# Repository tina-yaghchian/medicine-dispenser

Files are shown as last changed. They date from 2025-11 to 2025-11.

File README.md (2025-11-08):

# 💊 Automated Medicine Dispenser

[]()


An embedded **medicine dispenser** using two STM32 Nucleo-F401RE boards (UART), a **servo-driven** rotating mechanism, and a **hatch** for timed dispensing.

## 🗺️ System Diagram
System Architecture

## 💡 Idea Sketch
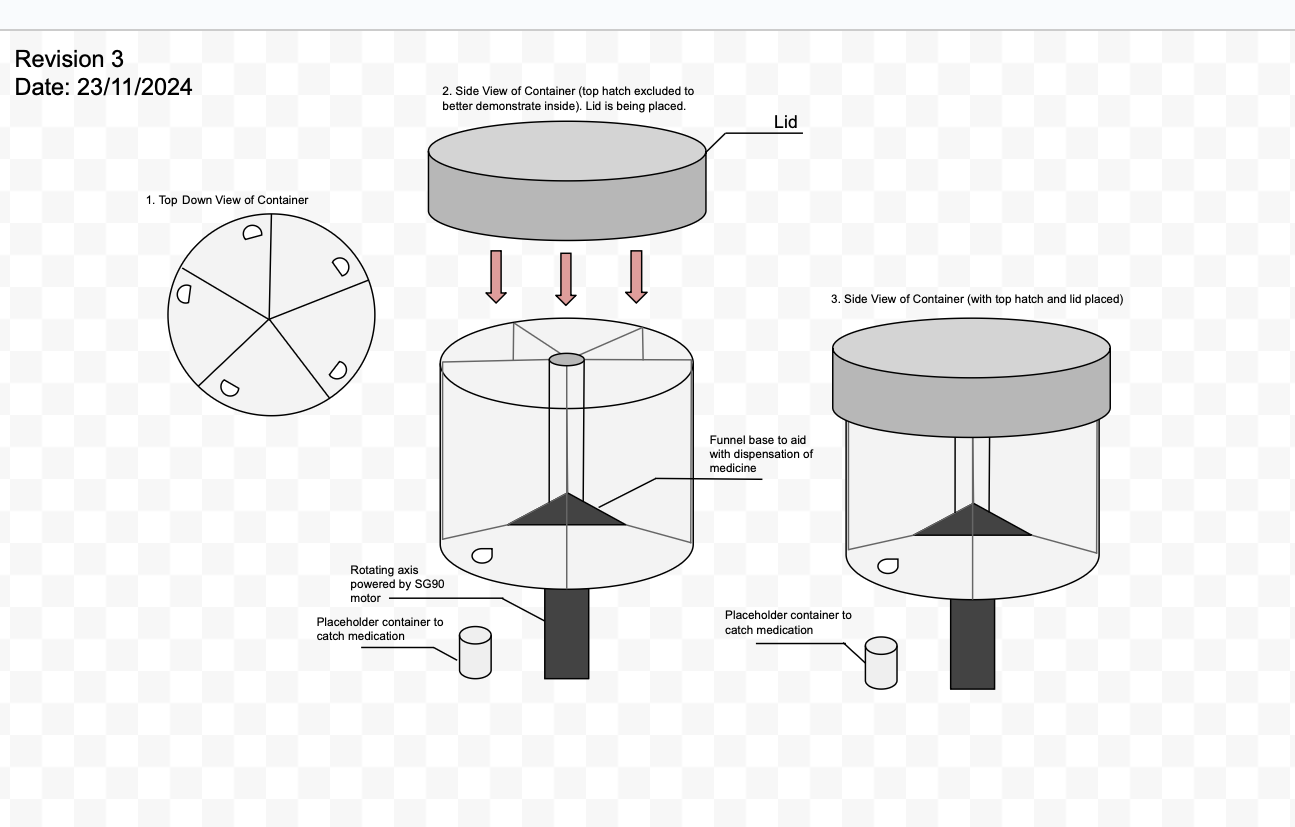
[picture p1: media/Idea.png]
Concept sketch


## 💊 CAD Models

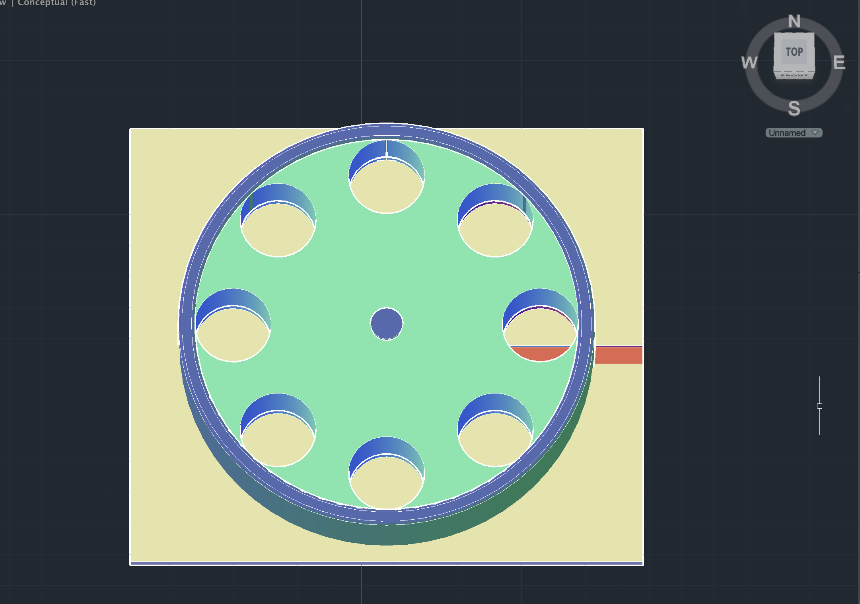
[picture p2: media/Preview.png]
3D Modeling


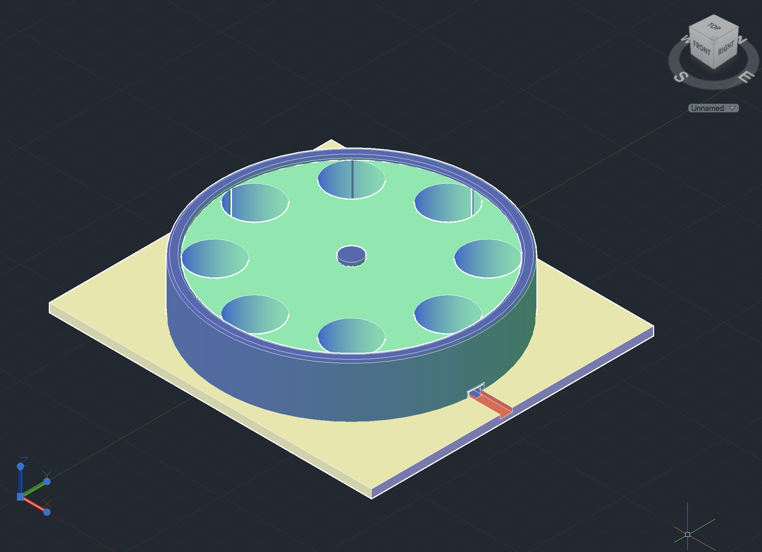
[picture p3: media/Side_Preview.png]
3D Modeling (side)


[medicine_dispenser.dwg](./medicine_dispenser.dwg) | Final 3D AutoCAD assembly

> Designed and modeled in AutoCAD Desktop.

## 📦 Repo Structure
```
hardware/      CAD + circuits
firmware/      Board projects (input & dispenser)
docs/          Design report, test plan, manuals
media/         Photos, diagram, demo video
```

## ⚙️ Build & Flash (STM32CubeIDE)
1. Clone repo and open **STM32CubeIDE**.
2. Import `firmware/uart_controller` and `firmware/motor_driver` as existing projects.
3. Set toolchain to **Debug** (or Release), then **Build**.
4. Connect each Nucleo-F401RE via USB and **Run → Debug** (or **Run**) to flash.

### UART (example settings)
- Baud: 115200, 8N1
- Wire **GND–GND**, **TX(Board1) → RX(Board2)**
- Distance: 1–15 m (project spec)

## 🔌 Pins (example — adjust for your boards)
**Input Board**
- Buttons: PB0..PB7 (w/ 10 kΩ pulldowns)
- UART TX: PA2, RX: PA3 (typical)

**Dispenser Board**
- Servo (hatch): PB6 (PWM)
- Servo (rotation): PB7 (PWM)
- UART RX: PA3, TX: PA2

## ▶️ Demo Video (inline)
<!-- GitHub can render .mov; include HTML video tag for inline playback -->
<video src="media/Test.mov" width="640" controls></video>

If your browser doesn’t autoplay inline, download: [Test.mov](media/Test.mov)

## 📸 Prototype
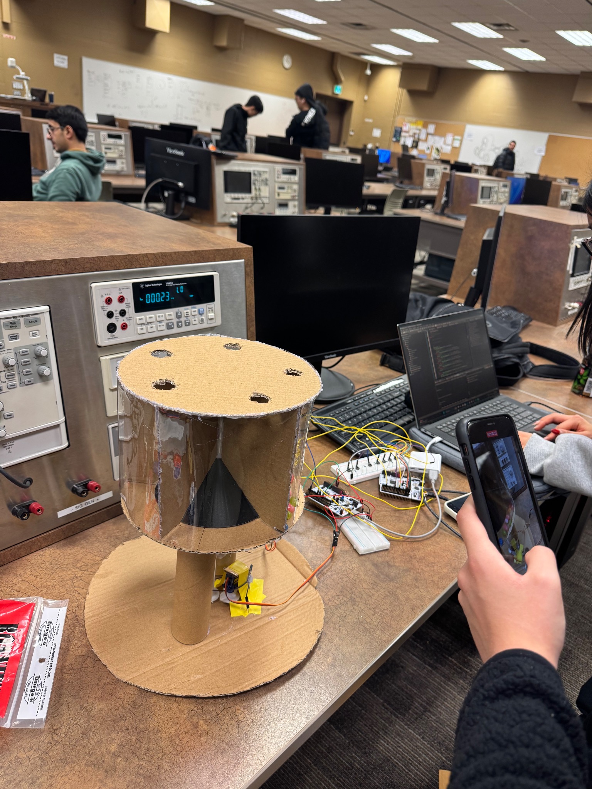
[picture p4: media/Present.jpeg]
Physical prototype in lab


## 🔌 Circuit Diagram
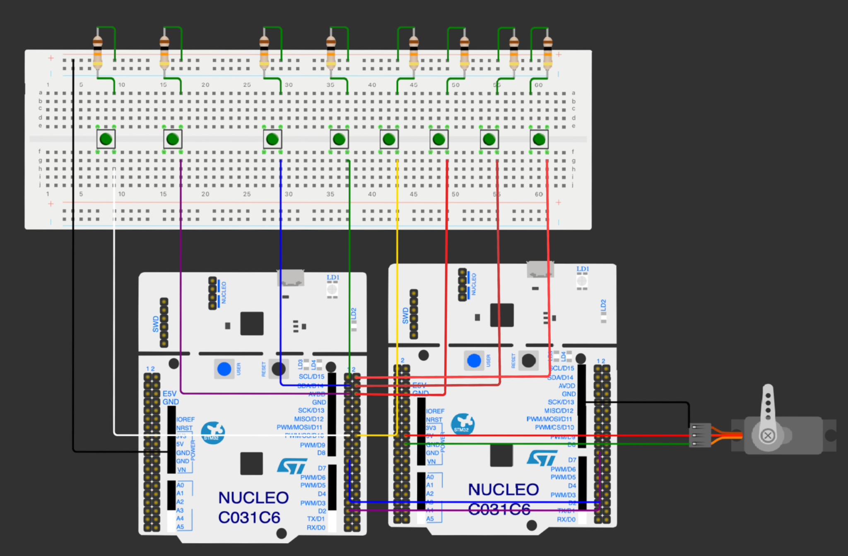
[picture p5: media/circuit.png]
Circuit diagram


## 🧪 Tests
- Communication ≥ 1 m
- Each of 5 compartments dispenses
- Accuracy within ±1 pill
- Supports 1–22 mm pills
- Total time < 10 min

## 🧰 Hardware & Tools
| Component | Model | Quantity | Function |
|---|---|---|---|
| Microcontroller | STM32 Nucleo-F401RE | 2 | Control & communication |
| Servo Motor | SG90 | 2 | Hatch & rotation control |
| Push Buttons | 6x6mm DIP | 8 | User input interface |
| Power Adapter | 5V DC | 1 | Power supply |
| Material | Polycarbonate (3D printed) | — | Mechanical structure |
| Software | AutoCAD, SolidWorks, STM32CubeIDE, Fritzing | — | Design & implementation |

## 📚 Docs
- Design Document: see `docs/` (add PDF version when ready)
- Test Plan: `docs/Test_Plan.md`

## 🚀 Future Improvements
- LCD display for scheduling and feedback
- BLE/Wi‑Fi companion app
- Stepper motor + home sensor
- Injection‑molded enclosure

## 🏁 License
MIT License © 2025 – Tina Yaghchian

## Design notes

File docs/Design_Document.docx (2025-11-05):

Design Document for a Medication Distribution Device to Aid Caretakers in Dispensing Medication

Parto Tolouashtiany, Tina Yaghchian, Ashley Moon

University of Waterloo

October 30, 2024

Needs Assessment

Customer & Challenge Definition

Client: Hospitals Nurses

Hospital Nurses: Employed nurses who work at a hospital to provide care to needed patients [1]

The Hospital Nurses that we are targeting are:

- Located in Canada
- Nurses in understaffed hospitals
  - A significant percentage of Canadian nurses have high work demands due to the limitation of nurses in hospitals, making them more prone to error. [2]
- Nurses in hospitals serving a demographic of elderly or chronically ill patients that require multiple dosages of pills and careful scheduling

Challenges

Medication error is a commonly made mistake made by hospital nurses due to the complexity of managing multiple medications, time pressures, and the risk of miscommunication which involves losing/misplacing pills or treating medicine at the wrong time.

According to reports, around 1/5 of registered nurses employed in a hospital admitted that medication errors occur “occasionally” or “frequently”. [3] More precisely, medication error was reported to exist among 57.4% of nurses. [4] This is likely due to high patient loads and the time constraints of such hospital environments which pose challenges in ensuring precise medication administration.

Competitive Landscape

To address the challenge associated with medication errors made by hospital nurses, here are three existing social, economic, and technological systems and how they address the challenges and their shortcomings.

1. Electronic Health Records Systems (EHR)

Electronic health record is a secure record that includes all of a patient’s health history. [5]

This system is also used to streamline medication management through automated alerts for medication reminders, advisories and alerts. However, there are shortcomings to this system. While EHR Alerts have been implemented to reduce miscommunication between nurses and effectively stay up to date with the medication schedule, they have been identified to cause alert fatigue and overload, leading to frustration. This ultimately leads to nurses ignoring important notifications, potentially resulting in oversights [6] .

2. Clinical Decision Support Systems (CDSS)

Clinical decision support systems assist healthcare providers by offering clinically relevant advice based on specific patient data. This system is also widely used to detect errors such as missing a prescribed medication or wrong dosages, ensuring patient safety. [7] This system, while effective, has had its pitfalls as listed below:

- Alert fatigue and inappropriate alerts
  - Research indicates that 95% of alerts generated by clinical decision support systems are often deemed irrelevant by physicians, leading to many alerts being ignored [8]
- Financial challenges
  - Financial barriers present a significant challenge, as approximately 74% of organizations utilizing CDSS report struggling with the cost-effectiveness of implementation [8]
3. Barcoding Medication Administration (BCMA) Systems

Barcoding Medication Administration (BCMA) systems are used primarily in hospitals to ensure that nurses and caregivers administer the correct medication to the right patient at the correct time. The system involves scanning barcodes on both patient wristbands and medication packaging, which helps reduce medication errors and enhances patient safety. [9] However, BCMA systems have several limitations. Training nurses and staff to use these systems can be time-consuming, impacting hospital resources. Additionally, the scanning process can slow down workflow, especially during busy shifts, and can feel tedious for nurses who must repeat this process multiple times daily.

Requirement Specification

Functional Requirements:

Aim of the System:

1. To contain and prepare 5 or more daily drugs to be administered to a patient.

- This number is based on the fact that around 1 in 5 adults aged 40-79 years in the United States and Canada use at least 5 prescription drugs. [10]
- Additionally, among this figure, it was more common for adults aged 60-79 to be taking 5 or more prescription drugs (in the US these figures were 34.5% vs. 14.5% and in Canada 30.9% vs. 10.4%) [11]

It is likely that caretakers who need to deal with multiple medications are those that struggle the most with organization, time allocation and medication accuracy when doing medication management. Our solution would most beneficially impact the sizably large population which need multiple medications (5+) managed by informal caretakers.

- To put into context, approximately 98% of aged 65 and older who receive publicly funded long-term home care services have informal caretakers [12]

2. To maintain accuracy when dispensing medication

As this device is a medical one, it is of the utmost importance that its margin of error be extremely minimal. The device is meant to eliminate common human error and as such cannot afford to make common mistakes. Ideally, it would have 100% accuracy when dispensing pills. However, this may not be the case, and as such, the lowest possible margin of error is ±1 pill in some test cases.

- To justify the need for such minimal errors, the gravity of them may be put into context: the Institute of Medicine (IOM) Committe on Quality of Health Care in the United States that medical errors are a leading cause of death and injury. [13]
- Further, medication errors themselves are the most common, preventable cause of patient injury. [14]

3. Confirmation indicator

Previous requirement: To indicate to the patient that their pills have been dispensed. This is done through audible and visual alert.

- The audible alert should be at a volume of 70 dB, as any volume above this is considered to cause a risk of hearing loss. [15]
- The volume was chosen to be at the very edge of the barrier to risk because an estimated 54% of Canadians aged 40-79 are reported to have hearing loss, which may make the alert less effective if the volume was lower [16]

We decided to remove this functional requirement as we figured that the pill dispenser should be efficient enough to be dispensed in a short amount of time, disregarding the need for an indicator. Furthermore, we determined that the sound produced by the gears during operation would be a sufficient indicator that the pill dispensing process has been completed. This auditory cue disregards the need for any additional signifiers.

Instead, we decided that the implementation of a confirmation button in the dispenser that finalizes the chosen number of pills could add an extra-step of user verification. This extra security reduces the risk of accidental pill dispensing and allows the user to confirm the initiation of the device. Confirmation buttons help reduce uncertainty and enhance accuracy before proceeding with any action [17]

4. To reduce the time spent sorting medications. The device is meant to eliminate a large burden on informal caretakers.

- An average of 1-3 hours is spent sorting prescription medications each week. [18]
- To minimize this time, the device needs to work efficiently and finish its task of dispensing pills at a faster rate. To minimize impatience, and demonstrate the devices efficiency, dispensing should take no more than 10 minutes at most.

Technical Requirements:

1. Communication

To communicate between two microcontrollers at a minimum distance of 1 meter between them. Additionally, the distance between them should not exceed a distance of 15 meters.

This is to reduce issues regarding signal degradation and interference as the microcontrollers will use UART communication, which is most reliable at shorter distances. Additionally, this range falls into the standard used for RS –232 serial communications, which while are not exact to what is being used here, can be a helpful comparison [19]

### 2. Pill Compartments: Preparing the Drugs

Regarding the pill compartments in our medical dispenser, we must consider the following components:

1. Flexibility: To cater to all pill sizes, the opening mechanism of the dispenser should be able to dispense multiple of any sized pill. Typically, pills are standardly less than around 5mm in diameter but can also range from 1mm to 22mm. The largest measurement we have is 22 mm, so the opening mechanism should be able to dispense pills up to that size.[20]

Previous Requirement: Adjustability

Adjustability: To cater to all pill sizes the pill-holding compartments should be either adjustable or flexible to ensure that a range of medications can be stored efficiently. Typically, pills are standardly less than around 5mm in diameter but can also range from 1mm to 22mm. The largest measurement we have is 22 mm, so the compartments should be able to sort pills up to that size.[20]

We decided to adjust this requirement because the ability to hold multiple types of pill components did not effectively account for dispensing the varying sizes of different pills.

2. Storage: Each pill compartment should have a secure locking mechanism to prevent spillage or unauthorized pill access. This is critical as unsecure access to medicine poses a risk to unprescribed individuals. For instance, reports indicate that approximately 50,000 children each year accidentally ingest medications without adult supervision, leading to emergency room visits. [21]

### 3. Software

The software used in a medicine dispenser plays a critical role in ensuring that caregivers and patients can easily program doses, set time schedules, and configure alarms. A well-designed, easy-to-navigate interface helps prevent errors and enhances user experience, particularly for non-technical users such as elderly patients or caregivers.

The software interface should be simple and straightforward, with clear instructions and logical flow. This reduces the likelihood of errors when setting doses or alarms. Buttons, icons, and labels should be large and easy to read, especially for users with visual impairments. [22]

4. Low Power Operation

Previous requirement: High Accuracy Sensors

A fundamental technical aspect of the medicine dispenser relies on sensor technology. To accurately dispense the pills and track the quantity of pills dispensed, we plan on using weight sensors.

A weight sensor is a type of transductor that measures weight. It transforms mechanical forces such as load, weight, tension, compression, or pressure into an electrical signal which is applied based on the force applied. [23]

For our dispenser, the weight sensor will convert the mechanical force of the pill’s weight into an electrical signal. Given that the average weight of American tablets range between 0.22g and 0.3235g, the weight sensor will be designed to measure forces within in range, with an accuracy of ± 0.001g. [24]

We decided to remove this technical requirement because the sensor sensitivity required for accurate weight measurement could not be achieved, as weight sensors are not precise enough for our needs. Thus, we decided to change this technical requirement to low-power operation.

Our medical dispenser is created with the intention of long-term and continuous use in hospital settings, making minimal energy consumption a must. The minimization of energy consumption can ensure an efficient, reliable, and safe operation of the medical dispenser with reduced wear and tear. [25]

For our dispenser, we set the power limit to be under 30 watts.

Safety Requirements:

1. Protective Cover

Previous requirement: Alarm

There should be an alarm in case the dispenser detects a malfunction within a short amount of time (Under 1 minute). It should ensure the dispenser accurately measures and dispenses the correct dosage. It is necessary to implement systems to alert caregivers and patients if a dosage is missed or incorrect. There should be large indicators for dosage and timing information and Intuitive controls to minimize user errors. [26]

We decided to omit the alarms as we decided to remove the high-accuracy sensors. Instead, we decided to implement a protective cover over the dispenser’s release area that only opens when dispensing the medication. This enhances safety by reducing the risk of accidental spills or unintended access, as covers and seals can effectively contain all spillage. [27]

2. Voltage Limit

Based on the safety guidelines for low-voltage electrical systems, there should be a limit to the voltage that the system uses (<50V) to avoid electrical hazards. A backup battery or an alternative power source must be included to ensure the dispenser operates during power outages. [28]

Analysis Assessment

Design

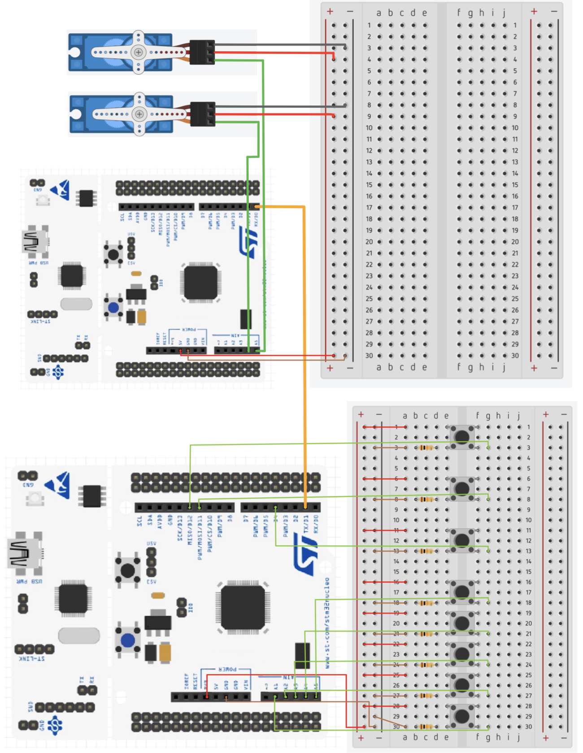
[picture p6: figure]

Design graphics used from Tinkercad and Fritzing software

Alternative Designs

1. Dispenser with Separated Funnel Containers

An alternative design which was considered had the containers of the dispenser fully separated. Instead of a large cylindrical container partitioned by 5 walls, 5 containers would be held aloft independent of each other. Tubing from each would join together into one larger tube, which would then dispense medication. Each container would have its own motor, which would open a hatch, allowing pills to be dispensed.

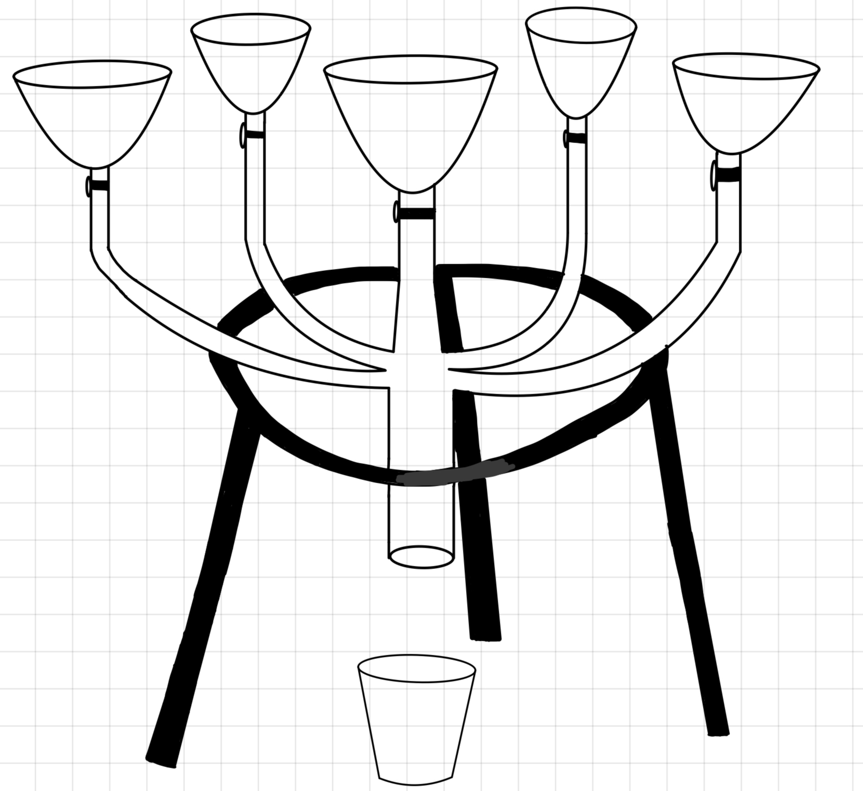
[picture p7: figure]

Alternative 1: Rough Diagram for Visualization

It was decided that this design would use an unnecessary number of motors. This would use a greater amount of energy and make the mechanism more complex, giving it more potential points of failure if anything malfunctioned.

2. Dispenser with Individual Rotating Containers

Another alternative was to have 5 individual containers which would rotate on top of a flat, stationary plate. Instead of a large cylinder divided by 5 walls, the separate containers would be attached to the moving axis directly. The containers would move over the hatch to dispense medication.

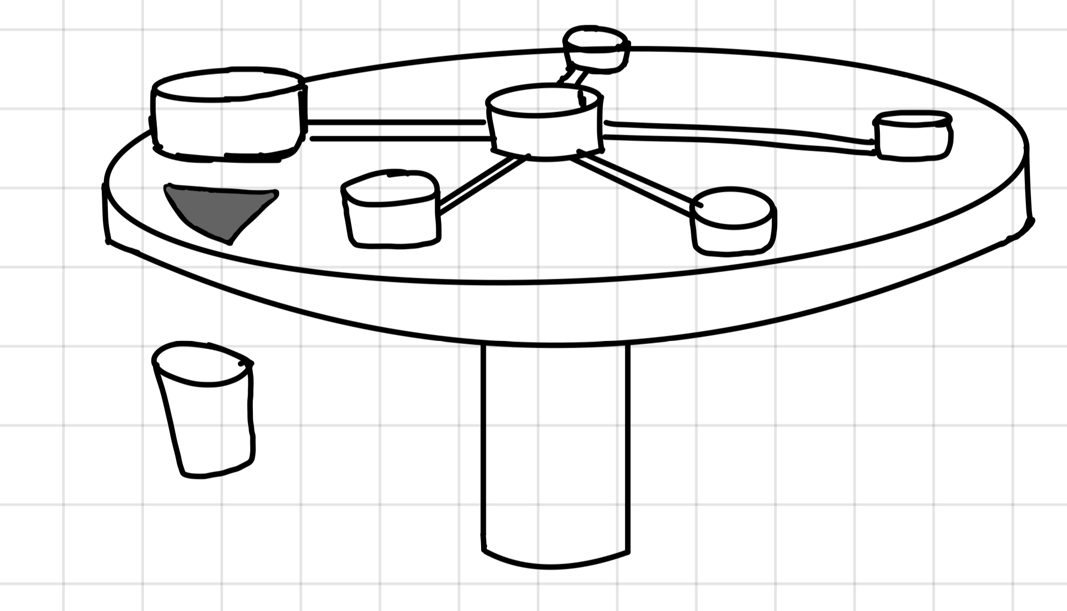
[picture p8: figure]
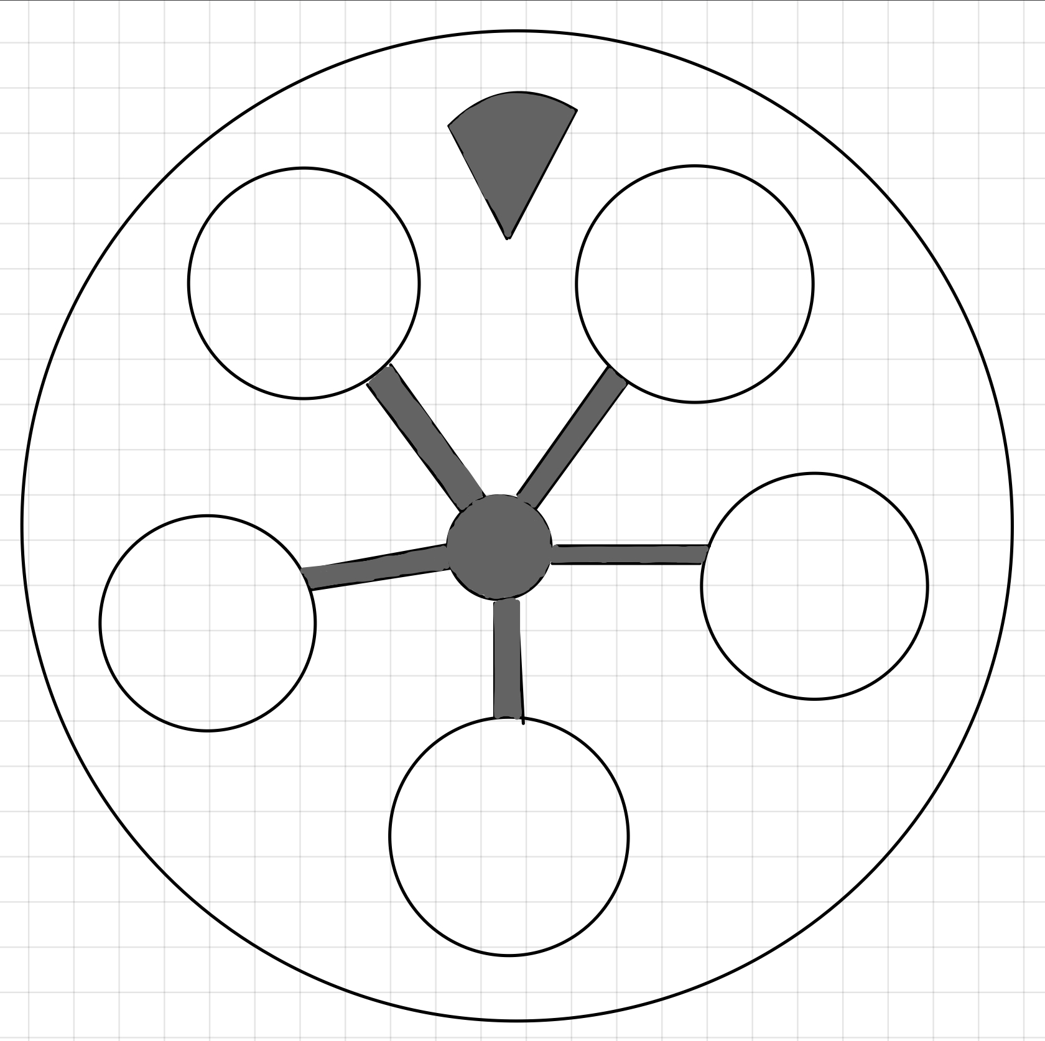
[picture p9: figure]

Alternative 2: Rough Sketch of Side View and Bird’s Eye View Perspectives

It was determined that this design does not efficiently use space and materials. It holds a much smaller volume of pills than the finalized design. This would cost a user more time when using the device, as they would have to restock it more often.

3. Dispenser with Rotating Container to Catch Pills Instead of Rotating Pill Compartments

This alternative would have had the pill containers stay stationary on a fixed metal plate. Each container would have a hatch underneath, where it would deposit pills into a cup underneath. The cup itself would be able to rotate, moving positions to underneath each hatch.

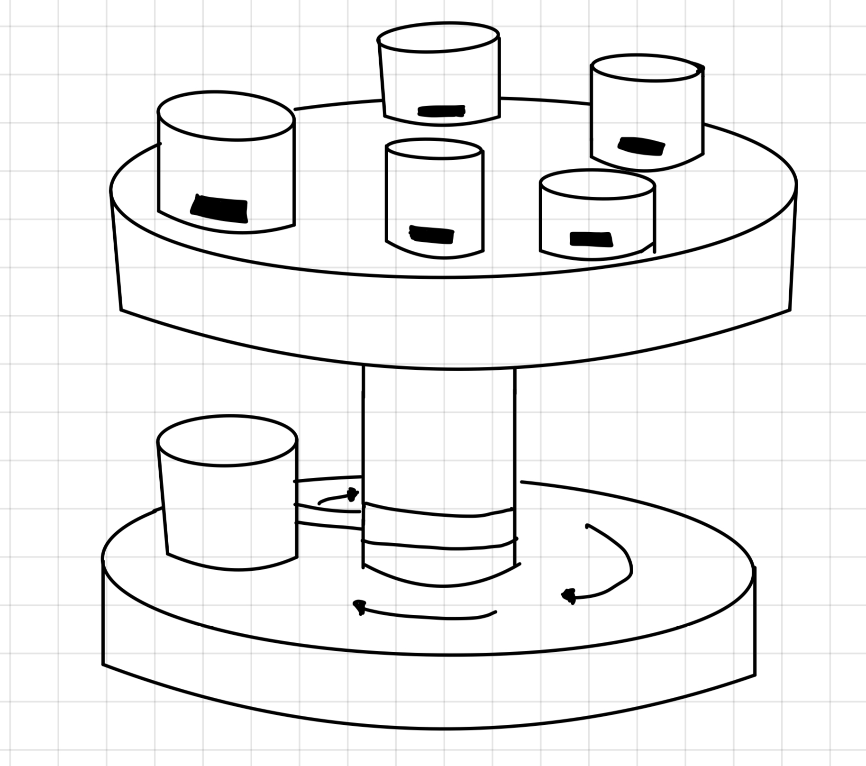
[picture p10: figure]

Alternative 3: Rough Diagram for Visualization

This alternative posed a similar issue to alternative 1. Instead of programming one hatch, now 5 would need to be programmed with 5 motors, in addition to creating a mechanism which would allow the cup to move. This would introduce too many variables and potential points of failure, making the solution too complex.

4. Dispenser using a Stepper or Gear Box Motor

This alternative is extremely similar to the finalized design, however instead of using a servo, a stepper or gearbox motor was to be used instead. After much deliberation, it was determined both motors would be too complex, needing a driver whose current would have to be limited to meet the specifications of the project. By contrast, the servo could be plugged directly to the microcontrollers, using less energy and working effectively if used with gears at a 1:2 ratio. As such, this alternative is almost the same as the finalized design, however, does not include gears and requires 2 drivers and far more extra code.

5. Horizontal Version of the Dispenser

Briefly, an alternative version of the final design was considered where, instead of the cylinder being vertical, it was instead horizonal. The walls would shift the pills up and down around the axis instead of circling around. The hatch would be on the walls of the cylinder instead of its floor.

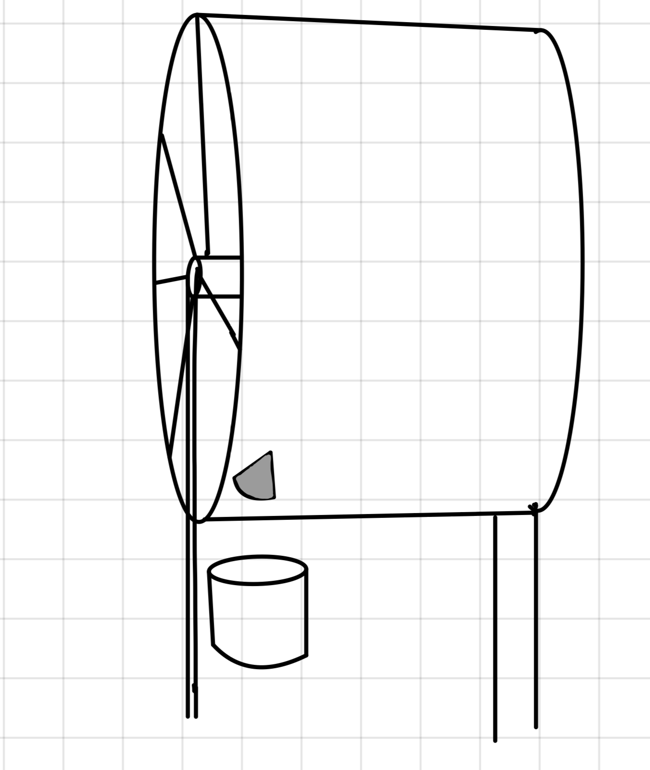
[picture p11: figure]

This design was ultimately not used as it was deemed more difficult to execute. The hatch would have to be curved to match the walls of the cylinder which would be more difficult to manufacture. Further, more torque would be needed by the motor in order to fully shift the pills around the axis.

Physical Construction

Base Material:

Motor: SG90 servo motor

Material: Cardboard, 3D printed

Power Supply: AC/DC adapter

NOTE: If adjustments are made to any of the dimensions, all dimensions should be scaled accordingly

Step 1: Creating the rotating walls

- Cut out 5 polygons with the following dimensions:

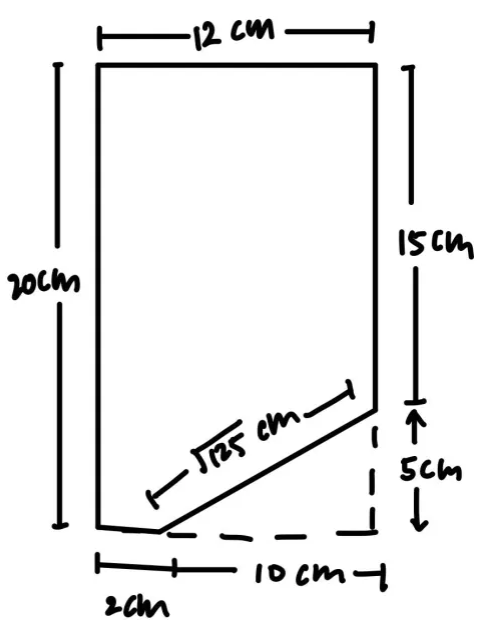
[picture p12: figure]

- These walls will be used to separate and hold the pills

Step 2: Create the base vertical rod

- Get a rod that is 4cm in diameter 35cm long
- This will be the base vertical rod which will hold all the parts together and in place

Step 3: Wall Ramps

- Cut out 10 rectangles with the dimensions of 6cm to 1cm
- Attaching the ramps
  - To figure out the angle at which the ramps should be attached, we will investigate the kinetic friction of pharmaceutical tablets and capsules
    - We will be 3D printing with the polycarbonate material
    - The kinetic friction coefficient for polycarbonate is approximately 0.33, influenced by both the surface and the tablet properties. Research shows that a ramp angle greater than 18 degrees is needed for smooth dispensing.[29]
- Attach these ramps on either side of each wall on the slanted portion by a 80 degree angle from the vertical (or 20 degrees from the horizontal > 18 degrees)
- These ‘ramps’ will help the pills move as the walls rotate

Step 4: Attach the walls on to the rod

- Attach each of the walls evenly on the end of the base vertical rod by the 15cm end so that the 12cm end is of the bottom of the rod

Step 5: Slanted base

- For our slanted base, we will be 3D printing
  - Use a CAD software (we will be using SolidWorks)
  - Create a base circle of radius of 12cm
  - Set this circle as the base of the cone
  - Draw the cone by using the cone tool or create a triangle profile that edges of the base circle to the point (apex)
  - Create a hole for the vertical base rod to go through
    - Add a cylinder with the radius of 2cm that extends through the cone
    - Use the subtract function to remove the cylinder from the cone to create a hole
  - Set the settings
    - Adjust the print settings as needed
    - For the cone, we will be using polycarbonate for its strength and durability
- Attach the slanted base 15cm below the top of the vertical rod with adhesive
- The structure should look something like this

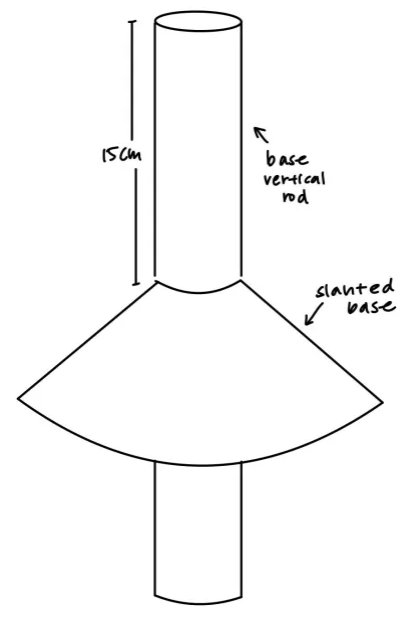
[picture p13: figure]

- (This is illustrated without the walls for clarity; the walls should be present at this step of the construction.)
- This will form a base layer / floor where the pills will be stored

Step 6: Base

- Cut out a circle with a radius of 16cm
- Cut out a hole in the middle of the circle with the diameter of 4cm
- This will be the main base of the system

Step 7: Hatch Opening

- Cut out a circular segment for the pills on the base within 2cm from the edge with the following dimensions shown below
- Cut out a circle with a diameter of 0.3cm directly above the point of the circular segment
- Attach the base by inserting the rod through the hole and positioning it directly beneath the cone. Secure it to both the bottom of the cone and the rod.
- The opening should look something like this when viewed from a bird’s-eye perspective

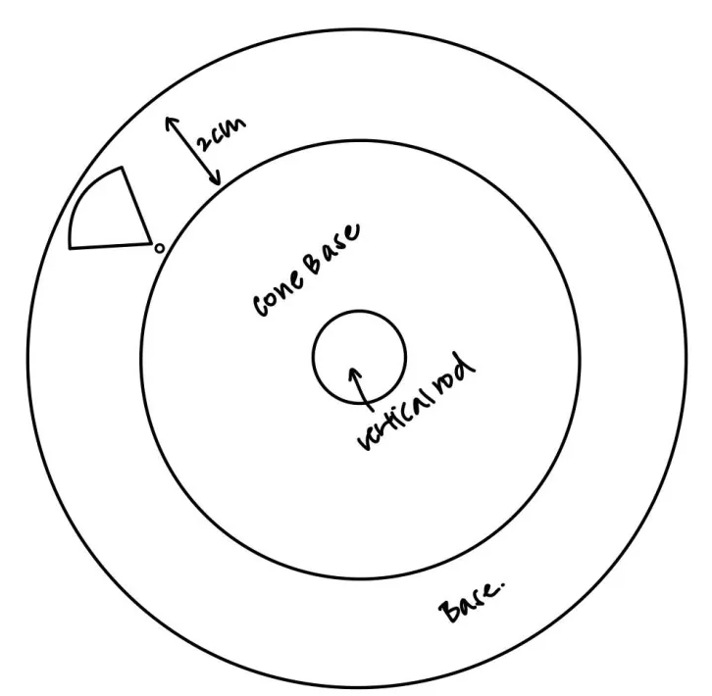
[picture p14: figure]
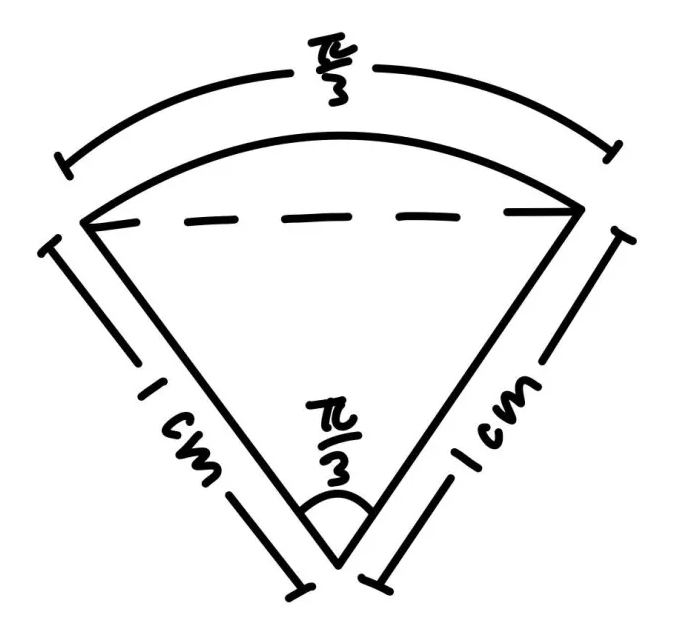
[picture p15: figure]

- (This is illustrated without the walls for clarity; the walls should be present at this step of the construction.)
- Attach the rod to the bottom of the slanted base by connecting it to both the rod and the base of the cone.

Step 8: Attach the hatch

- Cut out circular segment with the following dimensions

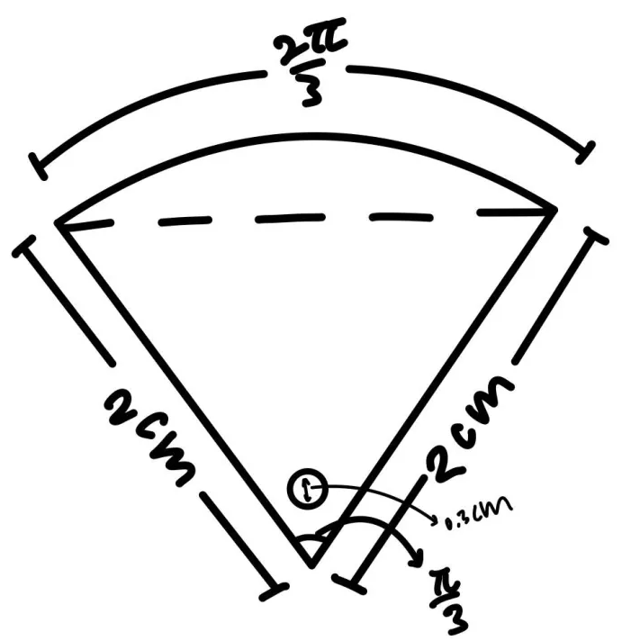
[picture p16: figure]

  - Remember to cut out a hole with a diameter of 0.3cm as close to the pointed corner as possible
- This will be the flap
- For the flap to be attached to the base, we will 3D print a rotary mechanism that also attaches the flap to the base which will look like the image below:

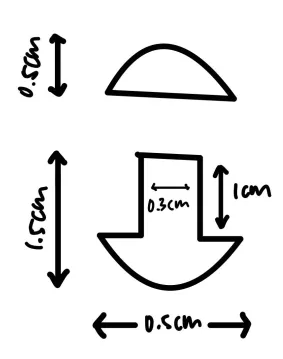
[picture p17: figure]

  - This mechanism will be 2 pieces and will be attached to each other later
- To create the rotary mechanism:
  - Like earlier, use SolidWorks
  - For the top piece
    - Create a sphere with a diameter of 0.5cm
    - Subtract half of the circle by using the subtraction tool
  - For the bottom piece
    - Create a sphere with a diameter of 0.5cm
    - Subtract half of the circle by using the subtraction tool
    - Attach a cylinder with a diameter of 0.3cm and a height of 1cm
- Attach the flap to the bottom piece through the hole with some adhesive
- Next put this through the circular hole made in the base plate – remember to not attach it
- Attach the top piece to the body of the bottom piece with adhesive – remember that it should not be attached to the base
- Attach the bottom piece to the servo horn with adhesive and the motor to the bottom of the base
  - See the overall detailed drawing for clarity
- This should now allow the motor to control the opening and closing of the circular segment hole

Step 9: Create an enclosing

- To create an enclosing for the top and the sides of the assembly:
- Cut out a rectangle with the dimensions: 20cm x 32πcm
- Cut out a circle with the diameter of 14cm
- Form an open cylinder by wrapping the rectangular piece around the edges of the circle
- Secure this by attaching it to the base and the rod with adhesive

Step 10: Platform

- Cut out a circle with a diameter of 14cm
- Create a hole with a diameter of 4cm

Step 11: Supports

- Attach four 15cm vertical rods evenly beneath to the platform
- This will support the system, allowing space underneath to catch any dispensed pills

Step 12: Rotating Rod

- To get the main vertical rod to rotate we will be using another SG90 motor and 2 gears of difference sizes of 1-2 ratio
  - Insert the vertical rod through the larger gear
  - Attach the smaller gear directly to the SG90 motor
  - Firmly secure the SG90 motor to the platform to prevent any movement during operation and ensure that the gears maintain proper alignment
- This will enable the main vertical rod to rotate through a gear mechanism

Detailed Overview of the Construction

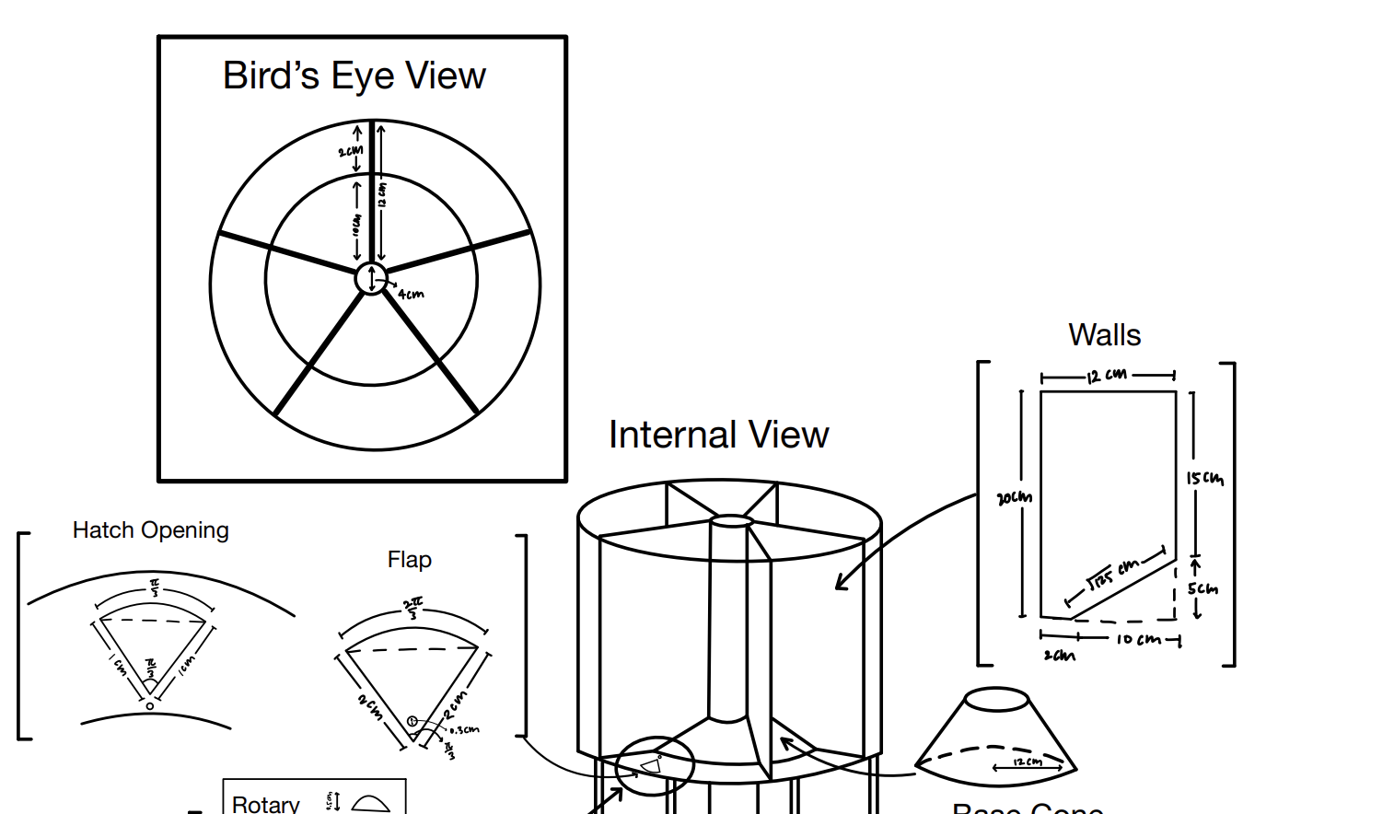
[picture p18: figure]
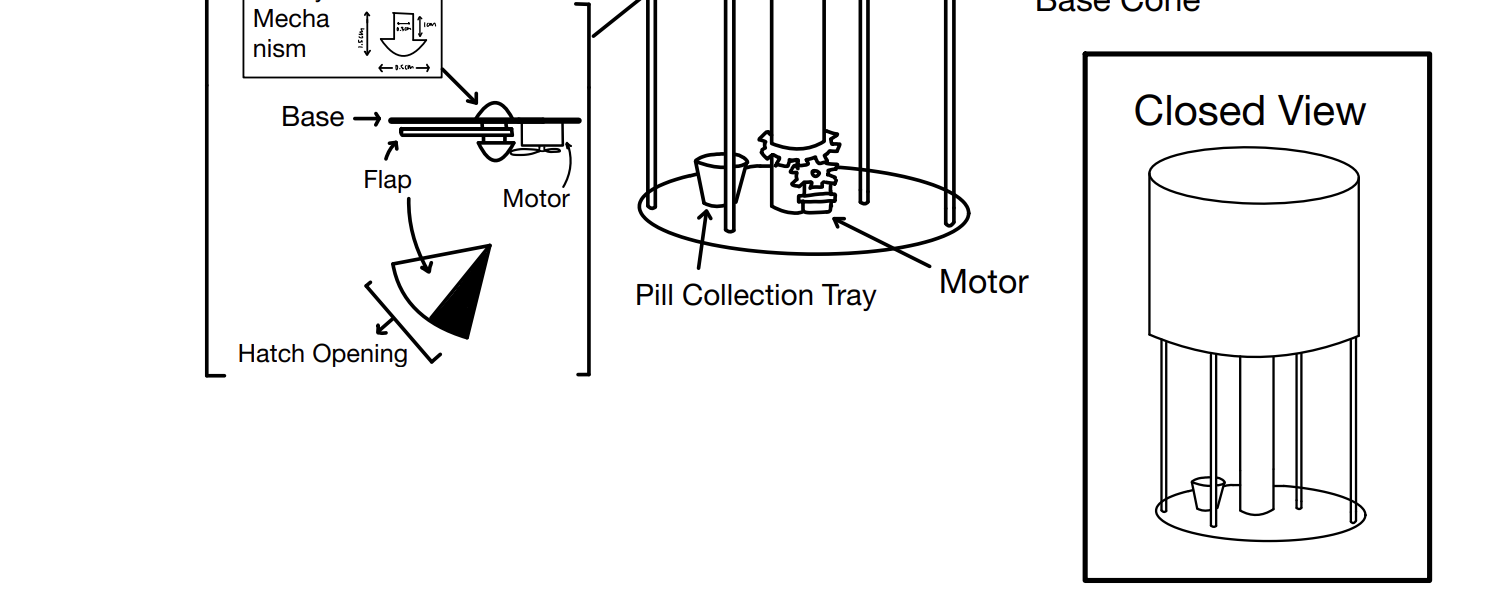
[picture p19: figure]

Code

Code for the first microcontroller

The first microcontroller will receive input through buttons that determine the number of pills to dispense. When the user presses the confirm button, the total is converted into an open-time duration for the hatch and sent to the second microcontroller. The second microcontroller then uses the recieved information to rotate the motors

Code for the first microcontroller

1. Set up and initialize the GPIO Pins the buttons
  a. Attach 8 buttons to GPIO pins, 5 for setting the pill type, 1 for resetting and 1 for confirming the selection, and 1 for increasing the pills
2. Set up serial communication
  a. We will use UART connection for its efficiency in reliable and long-distance data transmission
  b. Since the first microcontroller is controlling the communication, initialize it as a master
  c. Set an address for the second microcontroller for targeting the transmission
3. Define button functions
  a. For the count button, each button press will increase the pill count by 1
  b. 5 buttons will be used to initialize them to each pill type
  c. Use a count variable to store the total number of pills selected for each pill
  d. Write a function to reset all count variables when the reset button is pressed
  e. The last button will be a confirm button (function is listed below)
4. Convert pill count to time
  a. Calculate the hatch open time based on the pill count
    i. Find out the hatch open time per pill (We will use a default value of 1 second)
    ii. The total open time can be calculated with the formula: total open time = pill count x hatch open time
    iii. Convert this value to ms (This value will be our PWM pulse witch for the motor on the hatch)
5. Send data on the confirm button press
  a. When the user presses the confirm button, send the calculated time value to the second microcontroller

Code for the second microcontroller

Logic flow chart:

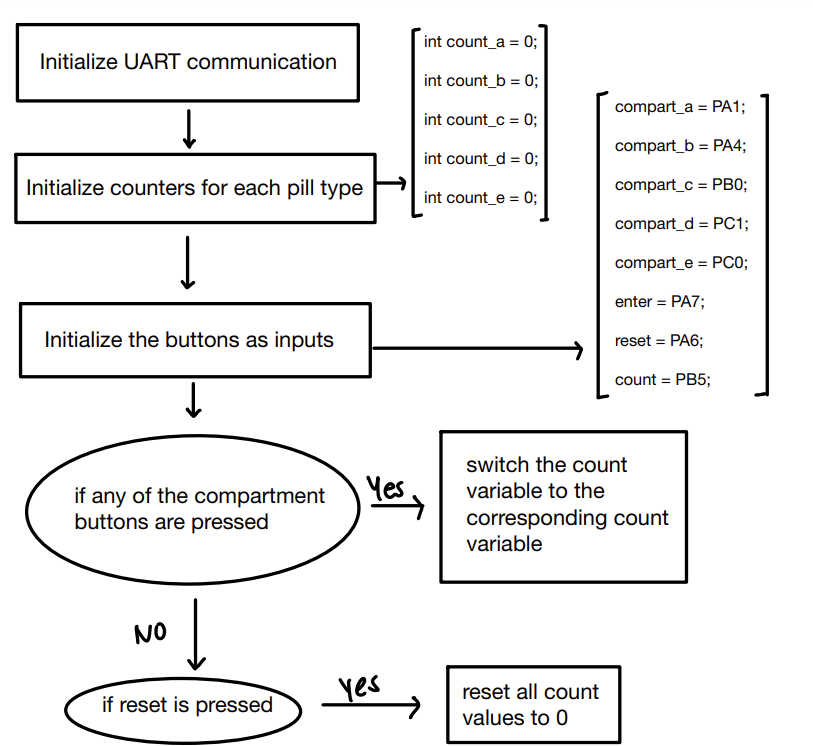
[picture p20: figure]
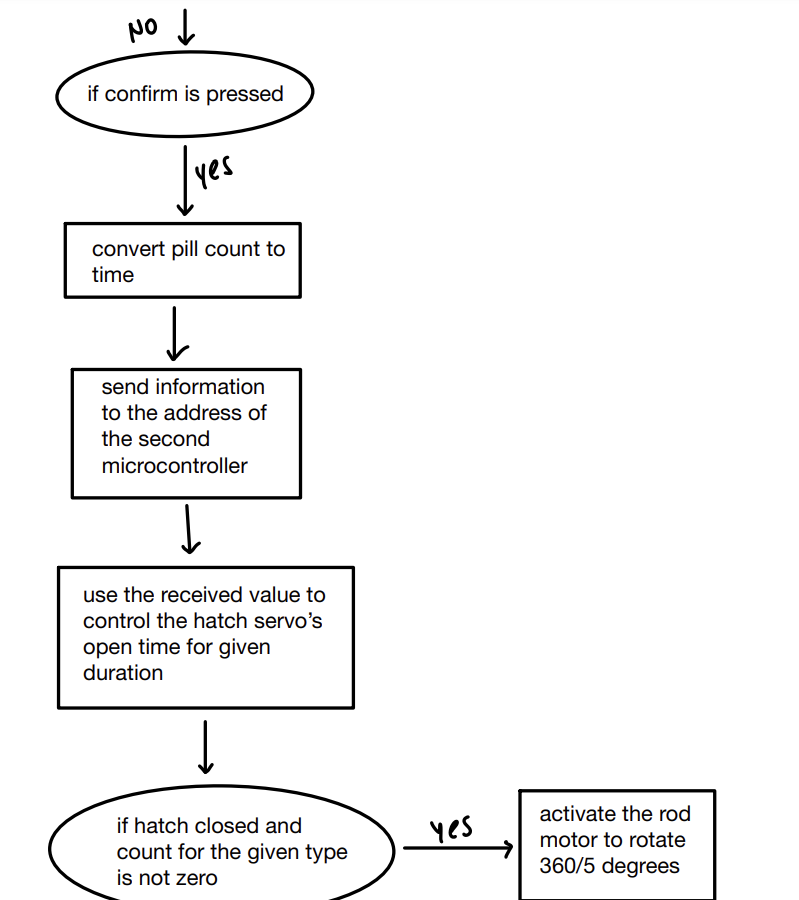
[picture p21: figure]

Technical Analysis

1. Engineering Standard: ISO 13485 – Medical Devices Quality Management Systems

ISO 13485 is a standard in the medical device industry’s quality management system focused on medical devices. It specifies that the devices are consistently designed and manufactured to meet the customer’s needs and the regulatory requirements. [30]

In our project, compliance with this standard’s requirements of quality assurance means to ensure that each medicine dispenser operates consistently and accurately to reduce the possibility of dispensing errors.

2. Scientific Principle: Feedback Control Systems

Feedback control systems are used to maintain the desired performance levels using a feedback loop and consist of 5 components: input, process being controlled, output, sensing elements, controller and actuating devices. [31]

For our project, the integration of these 5 basic components would be:

1. Input: Desired medication dosage and schedule set by the nurse and caregiver
- Indicates how much medication should be dispensed and when
- Depending on the patient, the timing of medication intake differs. Here are some common medicine schedules and the corresponding input:
  - Take 2 times daily
    - This generally means to take every 12 hours ( 24 / 2 = 12 )
  - Take 3 times daily
    - This generally means to take every 8 hours ( 24 / 3 = 8 )
  - Take 4 times daily
    - This generally means to take every 6 hours ( 24 / 4 = 6 ) [32]
2. Process being controlled: Dispensing mechanism of the medicine dispenser.
- Involves the act of sorting and dispensing the correct amount of medication at the scheduled times
3. Output: Dispensed medication
- Should match input requirements
4. Sensing elements: Sensors in the dispenser that monitors the dispensing process
- Checks the number of pills dispensed and the weight of the pills
5. Controller and actuating devices: Processes feedback from the sensors
- Actuating devices: motors, hatches

Through these 5 basic elements, our feedback loop will continuously monitor the output and compare it to our input. If any discrepancies are detected by our sensing elements, adjustments will be made to the actuating devices to correct the output. This ensures that the dispenser consistently delivers the correct dosage and the timing is specified.

3. Mathematical Principle: Trigonometry / Rotation Matrix

In our project, we can use a variety of trigonometric identities to calculate values to rotate and dispense pills in the medicine dispenser.

Here are some assumptions we will be making in our calculations:

1. The pills are positioned on a circular tray and are evenly spaced
2. The tray is centered at the origin and the pills are evenly distributed along the circumference of the circle.
3. There is an assortment of 5 pills

Use 1: Calculating the angular displacement:

Since we want the pills to be evenly spaced out, we can use the formula: (Δθ = 2π/n), where θ is the angular potion of each pill in radians, n is the number of pills (in our case, 5)

- If we sub in the values, we can get a value of 1.2566 radians
- This means that the tray needs to rotate by 1.2566 radians to move from one pill position to the next

Use 2: Determining the Coordinates of Each Pill to Determine Rotation Timing and Control

To determine the exact location of the pills on the circular tray, we can calculate its coordinates using trigonometry.

- The x and y coordinates for each pill can be found using the following equations:
- x = r cos θ,
- y = r sin θ,
- , where r is the radius of the tray and θ is the angular position of each pill with the values being: 0 radians, 1.2566 radians, 2.51327 radians, 3.7699 radians, 5.02655 radians

From here, we can use these coordinates and the rotational angle to align each pill with the dispenser using an angular rotation matrix.

Function Definition: A rotation matrix is used to complete a rotation in Euclidian space. [33]

The following equation:

can be used where x’ and y’ are the new coordinates after the tray has rotated by 1.2566 radians and x and y are the current coordinates of the pill before rotation.

This equation rotates the points, or in our case, our pills in the coordinate system we set up in the beginning and ensures that the pills are accurately positioned at the dispensing slot after each rotation.

Costs

Manufacturing and Implementation Costs

Bill of Materials (BOM)

(Boxes marked with a – indicated unavailable information)

Component | Model | Quantity | Description / Role in Design | Dimensions | Weight
Microcontroller | STM32 Nucleo Boards | 2 | Acts as the main control unit, coordinating all system operations | 10.16 x 7.62 x 2.4 cm | 20g
Servo Motor | SG90 Servo Motor | 2 | Controls the dispensing mechanism with accurate rotation | 23 x 12.2 x 29 mm | 9g
Push Buttons | Tact Button Switch 6x6x4.5mm 4Pin DIP Micro Panel PCB Momentary Tactile Tact Push Button Switch | 7 | Enables users to interact with the system, and start the dispensing process. | 6 x 6 x 4.5mm / 4 pin | 27g
Power Adapter | 5V AC/DC adapter | 1 | 5V adapter to supply power to the entire unit. | - | -
Jump wires | Jumper Wires Solderless Breadboard Jumper | 35 | Facilitates secure connections between components. | Of varying sizes | -
10KOhm Resistors | E-Projects 25EP51410K0 10K Ohm Resistors, 1/4 W, 5% | 8 | Helps set all buttons to have a “low” output to the STM microcontroller. Once a button is activated, the output will change to “high”. The resistors help assure the correct input of the buttons | 7.62 x 0.64 x 5.08 cm | 10 g
3D Printing Filament | Transparent PC Filament 1.75mm Clear Polycarbonate Filament | 1 | The filament will construct the durable structural elements of our design. | 1.75mm | -

Component Manufacturers and Vendors/Distributors

Component | Manufacturer | Location of Manufacturer | Vendor/ Distributor | Location of Vendor
Microcontroller | Espressif Systems | Shanghai, China | Electro- Meters | Pickering, Ontario, Canada
Servo Motor | TowerPro | Shenzhen, Guangdong, China | RobotShop | Quebec, Canada
Push Buttons | Omron Corporation | Kyoto, Japan | Future Electronics | Montreal, QC
Power Adapter | Arkare | Ontario, Canada | Amazon | Ontario, Canada
Jump Wires | IZOKEE | Ontario, Canada | Amazon | Ontario, Canada
Resistors | E-projects store | US | Amazon | Ontario, Canada
3D Printing Filament | CC3D store | Ontario, Canada | Amazon | Ontario, Canada

Installation Manual:

1. Introduction

This manual is meant for use by licensed medical professionals, technicians, and formal and informal caregivers. It details how to safely and correctly install the medication dispensing device.

2. Safety Precautions

- This device is only intended to be used with the included power supply (5V)
- This device must be placed on a flat, secure surface
- This device dispenses medication, keep out of reach of children, pets and other dependent individuals at risk
- Do not exceed the maximum capacity for each medicine compartment (do not allow compartments to overflow, leave at least 1cm of room between the lid and medication)

3. Assembly

- Unpackage and place device on a flat, stable and secure surface, (for example, a table or counter)
- Ensure that the microcontroller is correctly placed below the device, and that all wires to both motors are correctly connected
- Store the device in a dry environment (note: make sure that the device is stored at a temperature most appropriate for the medication being dispensed), and place the lid securely on top of the cylindrical container

4. Initial Setup and Testing

- Place the second microcontroller one meter away from the main device
- Place a minimal amount of medication in each compartment (for testing purposes)
- Turn both microcontrollers on and plug the device into its power source
- Set the desired amount of medication to be dispensed per compartment using the provided breadboard and buttons (Compartment 1, Compartment 2, Compartment 3, Compartment 4, Compartment 5, Count Button, Enter Button, Reset Button)
  - Note: See user manual for more detailed instructions
- Wait to observe the medication being dispensed

4. Maintenance

- Clean the dispenser and its compartments regularly using a dry or slightly damp cloth to avoid dust buildup
- Thoroughly clean before switching medications in each compartment
- Periodically check to make sure the motor, microcontrollers and buttons continue to work properly

5. Troubleshooting

- If the dispenser servo is unable to move each compartment, or is unable to open the hatch to dispense medication, or both:
  - Check to make sure its servos are fully functional (wiring is fully connected, path of servo is unobstructed, and it is correctly being powered)
  - Unplug the device and attempt to reset it
- If the dispenser is not receiving input from the buttons to determine the number of pills being dispensed
  - Check to make sure all buttons are securely wired and fully connected
  - Attempt to reset the inputs on the device using the Reset Button
  - Unplug/turn off the device and attempt to reset it

User Manual:

1. Introduction

This manual is meant to detail how to use the medication dispensary device.

2. Safety Precautions

- Refer to installation manual
- This dispenser was meant to hold medication, do not place other objects within as they may cause a hazard

3. Instructions

- To place medication in the device
  - Take off the lid of the device
  - Place medication (each type in a different compartment) within the containers
  - Place lid back onto the device
  - Plug the device into the provided power supply
- To input the number of medications to be dispensed
  - View the button system attached to the first microcontroller
  - Select which compartment (1, 2, 3, 4, 5) you wish to edit by pressing its corresponding button (see figure below)
  - After selecting the compartment, press the Count Button the same number of times as the amount of medication to dispense (for example, to dispense 3 pills, press the button three times)
  - Press the Enter Button to confirm the amount of medication to be dispensed
  - Repeat the above for all other compartments
  - To reset all amounts for each compartment, press the Reset Button

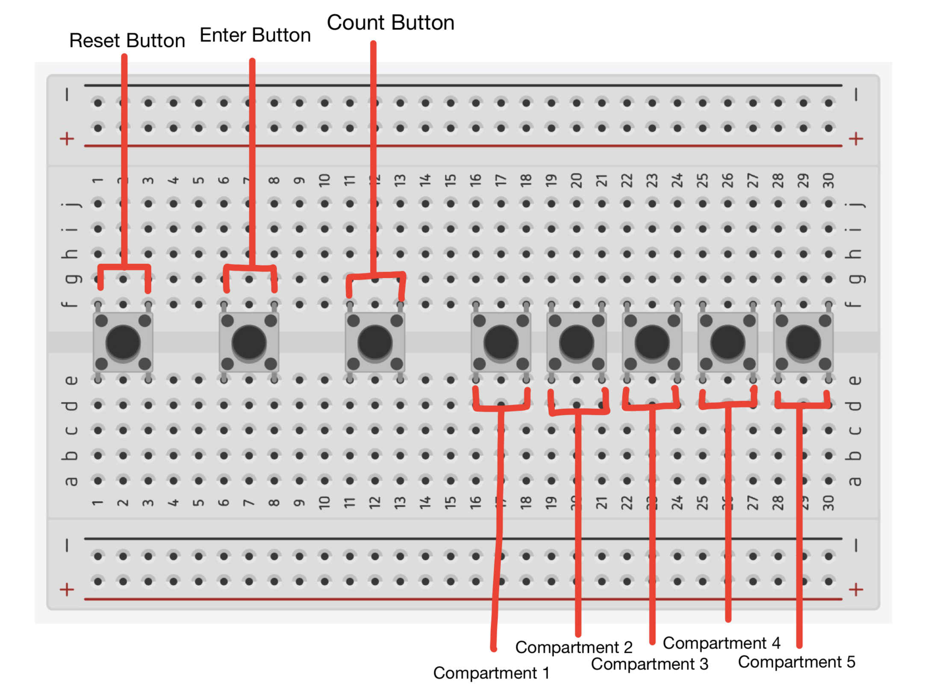
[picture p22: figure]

4. Maintenance

- Refer to installation guide

5. Troubleshooting

- Refer to installation guide

Risks

Energy Analysis

Reference Standard

We will break down the compartments by power level. The components not listed below do not consume power directly or has negligible power consumption.

STM32 nucleo-32 development board

- Power consumption: Maximum power supply of 5V and 300mA of current [34]

SG90 servo motor ( x2)

- Power consumption:
  - Typical power supply of 5V [35]
  - 500 mA of current [36]

AC/DC Adaptor: Arkare 5V

- Power consumption: Maximum power output of 10W
- Compatibility with 110V AC Outlet and CSA Approval: The adapter has an input range of 100V-240V AC, making it compatible with a 110V outlet.
  - In addition, the CSA certification can be shown as below:

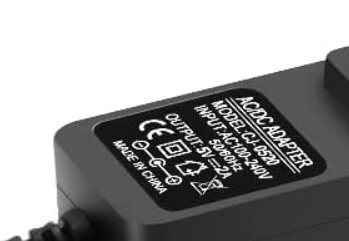
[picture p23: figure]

The calculations can be done as shown below since all power lines use 5V

Total current = 300 mA + 2 x 500 mA = 300 mA + 1000 mA = 1300 mA = 1.30 A

Power consumption = 5V x 1.30A = 6.5W

Therefore, according to our calculations, the dispenser should not exceed a power limit of 6.5W.

Possibility for significant energy storage

Significant energy storage cannot occur in our dispenser because it lacks components like batteries, capacitors, or any other mechanisms that store energy. The dispenser is made to directly consume energy by the dispenser’s motors, and other mechanisms as they operate without storing or transferring mechanical or electrical energy. In addition, the materials and geometries used in the dispenser are only used for dispensing; it does not contain any elastic, chemical, or elements that can store energy. This means that energy is fully used without any potential remaining storage.

Maximum total energy stored within the system under operation

Our dispenser operates sole on direct energy consumption provided by the AC/DC adapter

- Electrical energy
  - Supplied by a 5V power source and is immediately consumed by the components which all lack any form of energy storage to retain energy after use
- Mechanical energy
  - This is minimal as the servo motors and other moving parts are only in action for brief periods of time such as opening and closing the hatch mechanism
- Chemical energy
  - There are no chemical processes involved in the dispenser. Thus, there is no chemical energy being stored at any point

This confirms that there is no significant energy storage present in the system.

Project Limits

Our design complies with the following project limits:

- Utilizes less than 30W of energy
- Stores less than 500mJ of energy
- Does not use human test subjects
- Uses the STM32 nucleo board microcontroller

Risk Analysis

The design of our medication dispenser will account for the following possible ramifications accordingly.

Possible negative consequences on safety or the environment from intended use

1. Sustainability concerns on polycarbonate
- Polycarbonate is a strong, durable material; however, its production involves chemicals that can pose environmental risks if not managed properly. Additionally, the BPA in polycarbonate has the potential to leach into water sources, posing a threat to aquatic life and contributing to environmental toxicity.
- Polycarbonate is a strong and durable material, but its environmental impact is concerning. Producing polycarbonate requires using various chemicals, some of which can pose environmental risks if managed improperly. [37] In addition, the BPA in polycarbonate can be leached into water sources, posing a threat to aquatic organisms, and contributing to environmental toxicity. [37]

Possible negative consequences on safety or the environment from incorrect use

1. Cross contamination of medications
- If the patient of the dispenser gets changed and/or is used for multiple patients without proper cleaning, the hygiene of the dispenser becomes a risk for the patients as it can lead to something called pharmaceutical product cross-contamination.
- Pharmaceutical product cross-contamination occurs when foreign chemical, microbial, or physical substances are transferred from a substance to medicines. This can affect the purity and quality of the pharmaceutical products, potentially leading to negative health impacts to the users which can be life threatening and fatal [38]
  - To account for this, it is important to design the dispenser for easy cleaning such as including disposable or easily sterilizable components to ensure that the hygiene of the dispenser can be well taken care of.
2. Electronic Waste Disposal
- Since the device contains electronic components such as sensors, and microcontrollers, improper disposal of these components could create electric waste which poses the risk of long-term environmental hazards, especially when so much of them could be implemented in a singular hospital.
  - To account for this, we can create an instruction sheet that instructs the correct recycling method for the parts to ensure the safety of our environment.

Possible negative consequences on safety or the environment from unintended use

1. Using the device for non-medical purposes
- Use of the dispenser for objects that it was not designed for (such as liquid medication, non-standard pill sizes, or fragile pills) could result in jamming, malfunction, or incorrect dispensing.
  - To account for this, clear usage guidelines and warnings about compatibility will be implemented in the packaging of the device.

Possible ways that the design could malfunction and the consequences on the safety or the environment for each of the failure mechanism specified

1. Communication failure between the microcontrollers
- The communication link between the microcontrollers that configure the medication input could fail due to software glitches, interference, and/or wiring issues.
  - Consequence: This could lead to failure on the coordination between input commands and the dispensing action, leading to incorrect dispensing that could again result in overdosing and underdosing patients.
2. Wear and tear and moving parts
- The components in the dispenser that are in charge of the dispensing mechanism may wear out over time due to frequent use.
  - Consequence: This could lead to failures in the dispensing mechanism, such as pills becoming stuck or damaged, resulting in inconsistent or missed dosages. This increases the risk of overdosing or underdosing patients.

Testing and Validation

Test Plan

1. Distance between Two Microcontrollers Test

Requirement: To be able to communicate the number of pills needed from each compartment from one microcontroller to the other over a minimum distance of 1 meter

Interpretation: Ensure that the microcontrollers can communicate over a distance of 1 meter

Test Setup:

- Place device on a flat, sturdy surface (for example table or counter)
- Fill each compartment to 1/10 of the container height with a similar substitute for medicinal pills (for these tests, M&M candy will work as it will mimic the size of the average pill size), and secure lid of device
- Set the required number of pills to be dispensed from each compartment to 1 for all
- Place the first microcontroller with push button inputs 1 meter apart from the dispenser

Environmental Parameters:

- Environment must avoid all additional movement or bumps when experiment is being conducted to not interfere with dispensing mechanism
- The device should be tested at room temperature to avoid interference (timing and voltage irregularities) with UART communication
- The device should be tested in a room with low humidity as it can affect signal integrity over time (due to slight resistance changes caused by condensation)

Test Inputs:

- Operate the dispenser for one scheduled dispense cycle
- Input that each compartment should dispense 1 pill using the input buttons

Quantifiable Measurement Standard:

- The measurement standard is given meters, measuring the distance between the two microcontrollers
- Further to confirm that the dispenser is working, the number of pills being dispensed will also be measured and counted

Pass Criteria:

Pass: The microcontroller connected to the input buttons successfully sends input to the dispenser over a distance of at least 1 meter. (Note that the dispenser does not need to work well to pass this test, only indicate that it has received input)

Fail: The microcontroller is unable to sent input over a distance of 1 meter, the dispenser does not indicate that it has received any input

2. Dispensing Ability Test

Requirement: To contain and prepare 5 or more daily drugs to be administered to a patient

Interpretation: Ensure that all 5 compartments of the dispenser can dispense medication

Test Setup:

- Place device on a flat, sturdy surface (for example table or counter)
- Fill each compartment to 1/10 of the container height with a similar substitute for medicinal pills (for these tests, M&M candy will work), and secure lid of device
- Set the required number of pills to be dispensed from each compartment to 1 for all

Environmental Parameters:

- Environment must avoid all additional movement or bumps when experiment is being conducted to not interfere with dispensing mechanism

Test Inputs:

- Operate the dispenser for one scheduled dispense cycle
- Input that each compartment should dispense 1 pill using the input buttons

Quantifiable Measurement Standard:

- Count the number of pills dispensed to ensure it aligns with the expected value of 5 from each compartment
- From this you could calculate the percentage of how successful it was for each compartment if needed

Pass Criteria:

Pass: The dispenser must successfully dispense at least 1 pill from each of the 5 compartments

Fail: It is unable to dispense at least 1 pill from each compartment

3. Dispensing Accuracy Test

Requirement: To maintain accuracy when dispensing medication (change number of medication to be dispensed)

Interpretation: Ensure that each compartment can accurately dispense the required amount of medication

Test Setup:

- Place device on a flat, sturdy surface (for example table or counter)
- Fill each compartment to 1/10 of the container height with a similar substitute for medicinal pills (for these tests, M&M candy will work), and secure lid of device

Environmental Parameters:

- Environment must avoid all additional movement or bumps when experiment is being conducted to not interfere with dispensing mechanism

Test Inputs:

- Input should be provided for each compartment of the device, ideally being randomly generated from numbers (0-5)
- Input would be tested with randomly generated combination of numbers at least thrice to ensure consistency of dispenser
- From this you can calculate the percentage accuracy of the dispenser if needed

Quantifiable Measurement Standard:

- The number of pills dispensed from each compartment would be counted and compared to the provided input

Pass Criteria:

Pass: The input for each compartment is equal to the resulting number of pills from each compartment which were measured

Fail: The input numbers for each compartment and resulting number of pills from each compartment do not match

4. Variability in Pill Size Test

Requirements: To cater to all pill sizes, each compartment should be able to accurately dispense medication of sizes between 1-22mm

Interpretation: The device should be able to accurately dispense medication of varying sizes within this test

Test Setup:

- Place device on a flat, sturdy surface (for example table or counter)
- Fill each compartment to 1/10 of the container height with a similar substitute for medicinal pills (for this test, each compartment should have a different substitute of a varying size), and secure lid of device
  - Substitutes:
    - Beans
    - M&Ms
    - Silica gel beads
    - Tic Tacs
    - Almonds

Environmental Parameters:

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

Test Inputs:

- Input should be provided for each compartment of the device, ideally being randomly generated from numbers (0-5)
- Input would be tested with randomly generated combination of numbers at least thrice to ensure consistency of dispenser

Quantifiable Measurement Standard:

- The number of pills dispensed from each compartment would be measured through counting and compared to the provided input
- From this, the percentage accuracy of the dispenser can be calculated if needed

Pass Criteria:

Pass: The device must be able to consistently dispense the same number of pills per compartment as was indicated in the input

Fail: The device is unable to consistently dispense the same number of pills per compartment as was indicated in the input

5. Time Taken to Dispense Medication Test

Requirement: The dispenser must be able to save users time when sorting medication. As such, dispensing should take no more than 10 minutes at most.

Interpretation: The device must be able to consistently dispense medication in under 10 minutes when used

Test Setup:

- Place device on a flat, sturdy surface (for example table or counter)
- Fill each compartment to 1/10 of the container height with a similar substitute for medicinal pills (for these tests, M&M candy will work), and secure lid of device

Environmental Parameters:

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

Test Inputs:

- Input should be provided for each compartment of the device, ideally being randomly generated from numbers (0-5)
- Input would be tested with randomly generated combination of numbers at least thrice to ensure consistency of dispenser

Quantifiable Measurement Standard:

- The total time take for all medication to be dispensed for each compartment
- From this, the average time taken can be calculated if desired

Pass Criteria:

Pass: The dispenser can dispense all medication in under 10 minutes consistently

Fail: The dispenser is unable to dispense all medication, any medication or is unable to do so in under 10 minutes

Works Cited

[1] “Careers in health care,” ontario.ca, https://www.ontario.ca/page/careers-health-care (accessed Sep. 26, 2024).

[2] N. Li and K. A. Look, “The Association of Caregiver Characteristics and Caregivers’ Perceived Difficulty in Medication Management Tasks,” INNOVATIONS in pharmacy, vol. 13, no. 1, p. 16, Apr. 2022, doi: https://doi.org/10.24926/iip.v13i1.4523.

[3] InfoLAW: “Medication Errors,” Canadian Nurses Protective Society, Nov. 2021. https://cnps.c

[4] A. Jember, M. Hailu, A. Messele, T. Demeke, and M. Hassen, “Proportion of medication error reporting and associated factors among nurses: A Cross Sectional Study,” BMC nursing, https://www.ncbi.nlm.nih.gov/pmc/articles/PMC5848571/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,associated%20with%20medication%20error%20reporting. (accessed Sep. 26, 2024). a/article/medication-errors/

[5] “What’s an Ehr?,” eHealth Ontario, https://ehealthontario.on.ca/en/patients-and-families/ehrs-explained (accessed Oct. 30, 2024).

[6] “Designing effective EHR alerts: Smart toolkit,” Designing Effective EHR Alerts | SMART Toolkit | Ohio State Medical Center, https://smart.osu.edu/the-toolkit/ehr-alerts/#:~:text=EHR%20Alerts%20are%20a%20form,mediated%20reminders%2C%20advisories%20and%20alerts. (accessed Oct. 30, 2024).

[7] R. Awati, M. Charles, and A. DelVecchio, “What is a clinical decision support system (CDSS)?: Definition from TechTarget,” Health IT and EHR, https://www.techtarget.com/searchhealthit/definition/clinical-decision-support-system-CDSS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,wrong%20dosage%20of%20a%20medication. (accessed Oct. 30, 2024).

[8] R. T. Sutton et al., “An overview of clinical decision support systems: Benefits, risks, and strategies for Success,” Nature News, https://www.nature.com/articles/s41746-020-0221-y (accessed Oct. 30, 2024).

[9] S. Kunze, "The Role of Barcoding in Medication Administration," *Healthcare IT News*, 2023. [Online]. Available: https://www.healthcareitnews.com/

[10] “Top 10 Medical Errors That Lead to Death,” The Law Offices of Dr. Michael M. Wilson M.D., J.D. & Associates. https://wilsonlaw.com/fatal-medical-errors/#:~:text=Medication%20errors%20are%20one%20of

[11] “Products - Data Briefs - Number 347 - August 2019,” Centers for Disease Control and Prevention, 2019. https://www.cdc.gov/nchs/products/databriefs/db347.htm

[12] “Health System Performance Supporting Informal Caregivers- The Heart of Home Care,” 2010. Available: https://secure.cihi.ca/free_products/Caregiver_Distress_AIB_2010_EN.pdf

[13] R. A. Tariq and Y. Scherbak, “Medication Dispensing Errors and Prevention,” National Library of Medicine, 2024. https://www.ncbi.nlm.nih.gov/books/NBK519065/

[14] R. A. Tariq and Y. Scherbak, “Medication Dispensing Errors and Prevention,” National Library of Medicine, 2024. https://www.ncbi.nlm.nih.gov/books/NBK519065/

[15] “Decibel Chart: What You Need to Know”, National Council on Aging. https://www.ncoa.org/adviser/hearing-aids/decibel-levels/

‌[16] S. C. Government of Canada, “Unperceived hearing loss among Canadians aged 40 to 79,” www150.statcan.gc.ca, Aug. 21, 2019. https://www150.statcan.gc.ca/n1/pub/82-003-x/2019008/article/00002-eng.htm

[17] Utah Design System, https://designsystem.utah.gov/library/components/buttonsTags/confirmationButton (accessed Oct. 30, 2024).

[18] R. Stress, “Walberg Family Pharmacies,” Walberg Family Pharmacies, Nov. 14, 2022. https://www.walbergfamilypharmacies.com/our-pharmacist-recommends/reducing-stress-on-caregivers-by-eliminating-time-spent-sorting-medications (accessed Sep. 18, 2024).

[19] “Fundamentals of RS-232 Serial Communications | Analog Devices,” Analog.com, 2024. https://www.analog.com/en/resources/technical-articles/fundamentals-of-rs232-serial-communications.html

[20] Brooke, “Explaining drug tablet sizes, shapes, and packaging: Ascend,” Ascend Packaging Systems, https://ascendpkg.com/tablet-sizes-shapes-and-packaging/#:~:text=There%20are%20a%20variety%20of,about%20%3E5%20mm%20in%20diameter. (accessed Sep. 26, 2024).

[21] D. Budnitz and P. N. Malani, “Keeping medicine away from children,” JAMA, vol. 324, no. 6, May 2020, doi: https://doi.org/10.1001/jama.2020.7206.

[22] J. Wu, D. Jiao, C. Lu, C. Li, X. Huang, and S. Weng, “How Do Older Adults Process Icons in Visual Search Tasks? The Combined Effects of Icon Type and Cognitive Aging,” International Journal of Environmental Research and Public Health, vol. 19, no. 8, p. 4525, Jan. 2022, doi: https://doi.org/10.3390/ijerph19084525.

[23] “Weight Sensor | Measuring Weight | How it Works | FUTEK,” www.futek.com. https://www.futek.com/weight-sensor

[24] Weight variation and tablet friability. | download table, https://www.researchgate.net/figure/Weight-Variation-and-Tablet-Friability_tbl2_237725788 (accessed Sep. 27, 2024).

[25] 404, https://saveonenergy.ca/en/For-Business-and-Industry/Resources/Energy- (accessed Oct. 30, 2024).

[26] C. West, Fenerty, Feldman, Kaplan, and Davis, “The effect of reminder systems on patients’ adherence to treatment,” Patient Preference and Adherence, vol. 6, p. 127, Feb. 2012, doi: https://doi.org/10.2147/ppa.s26314.

[27] “Spill control,” Bryson, https://www.bryson.co.uk/cleaning-hygiene/waste-management/spill-control (accessed Oct. 30, 2024).

[28] IEEE, https://ieeexplore.ieee.org/ielaam/28/8490118/8286875-aam.pdf (accessed Sep. 18, 2024).

[29] An investigation into the kinetic (sliding) friction of some tablets and capsules, https://sci-hub.se/10.1016/j.ijpharm.2009.09.038 (accessed Oct. 30, 2024).

[30] “ISO 13485 - Quality Management for Medical Devices,” www.bsigroup.com. https://www.bsigroup.com/en-CA/Medical-Devices/Our-services/ISO-13485-Quality-Management/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

‌[31]“Automation - Feedback controls,” Encyclopedia Britannica. https://www.britannica.com/technology/automation/Feedback-controls

[32] “Not understanding what the directions mean”, Rate as good https://www.staffordshire.gov.uk/Advice-support-and-care-for-adults/Help-and-support-with-daily-living/Guidance/Taking-medicines-safely-and-effectively/FAQ/Q003.aspx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,divided%20by%206%20%3D%204).

[33] “Rotation matrix”, Wikipedia, https://en.wikipedia.org/wiki/Rotation_matrix

[34] STM32 nucleo-32 boards (MB1180) - user manual, https://www.st.com/resource/en/user_manual/dm00231744.pdf (accessed Oct. 30, 2024).

[35] “Servo Motor,” Servo Motor - an overview | ScienceDirect Topics, https://www.sciencedirect.com/topics/computer-science/servo-motor#:~:text=35%20shows%20a%20diagram%20of,if%20the%20load%20is%20light. (accessed Oct. 30, 2024).

[36] Docs.arduino.cc, https://docs.arduino.cc/learn/electronics/servo-motors/ (accessed Oct. 30, 2024).

[37] “Polycarbonate: Toxic chemicals in plastic,” Recycled Plastic, https://www.recycledplastic.com/polycarbonate-toxic/#:~:text=The%20presence%20of%20BPA%20in,it%20can%20harm%20aquatic%20organisms. (accessed Oct. 30, 2024).

[38] Ajol, https://www.ajol.info/index.php/ajb/article/viewFile/58629/46964 (accessed Oct. 30, 2024).

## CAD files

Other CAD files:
medicine_dispenser.dwg

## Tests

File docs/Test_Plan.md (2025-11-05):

# Test Plan – Automated Medicine Dispenser

## Tests
1. Communication Range (UART ≥ 1 m) – Pass/Fail
2. Dispensing Ability (each of 5 compartments dispenses) – Pass/Fail
3. Accuracy (±1 pill max) – Pass/Fail/Deviation Notes
4. Pill Size Variability (1–22 mm) – Observations per size
5. Time to Dispense (Total < 10 min) – Measured time

## Results Table (example)
| Run | C1 | C2 | C3 | C4 | C5 | Total Time (mm:ss) | Notes |
|-----|----|----|----|----|----|---|---|
| 1 | | | | | | | |
| 2 | | | | | | | |

## Notes
- Environment: temperature, humidity, distance, power supply
- Firmware version and UART baud rate

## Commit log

2025-11-08 Add final AutoCAD model (DWG)
    [medicine_dispenser.dwg]
2025-11-08 Add CAD Models section to README
    Added CAD models section with links to files.
2025-11-08 Fix image syntax for CAD models in README
    Updated image syntax in README for CAD models section.
